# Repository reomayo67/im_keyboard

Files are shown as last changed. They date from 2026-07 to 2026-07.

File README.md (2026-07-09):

# im_keyboard

 33% ergonomic layout Keyboard. Atmega32u4 powered



HAS NOT BEEN ASSEMBLED YET

ALOT of this is heaviliy inspired by ScottoKeebs, I am using his footprint and symbol libraries in kicad, so shoutout to him. He was a huge help in making this possible. [ScottoKeebs](https://github.com/joe-scotto/scottokeebs) Huge inspo from [Plaid](https://github.com/hsgw/plaid)

So I just wanted to make an intro into the hardware engineering space with a simple pcb mkb. This is my first ever officially documented project, so yea. Ive been wanting to make one for a while, and eventually want to evolve into making abuncha wacky ergo keyboards and other stuff like that.

this keyboard uses only through hole components and relies on a devboard. Any type of mx switch can be used, it is not hot swap ready though.





The Case is 3d printed, made with fusion360.

Here are the youtube videos i watched in order to make this

https://www.youtube.com/watch?v=7azQkSu0m_U&t=491s

https://www.youtube.com/watch?v=8WXpGTIbxlQ&t=3s

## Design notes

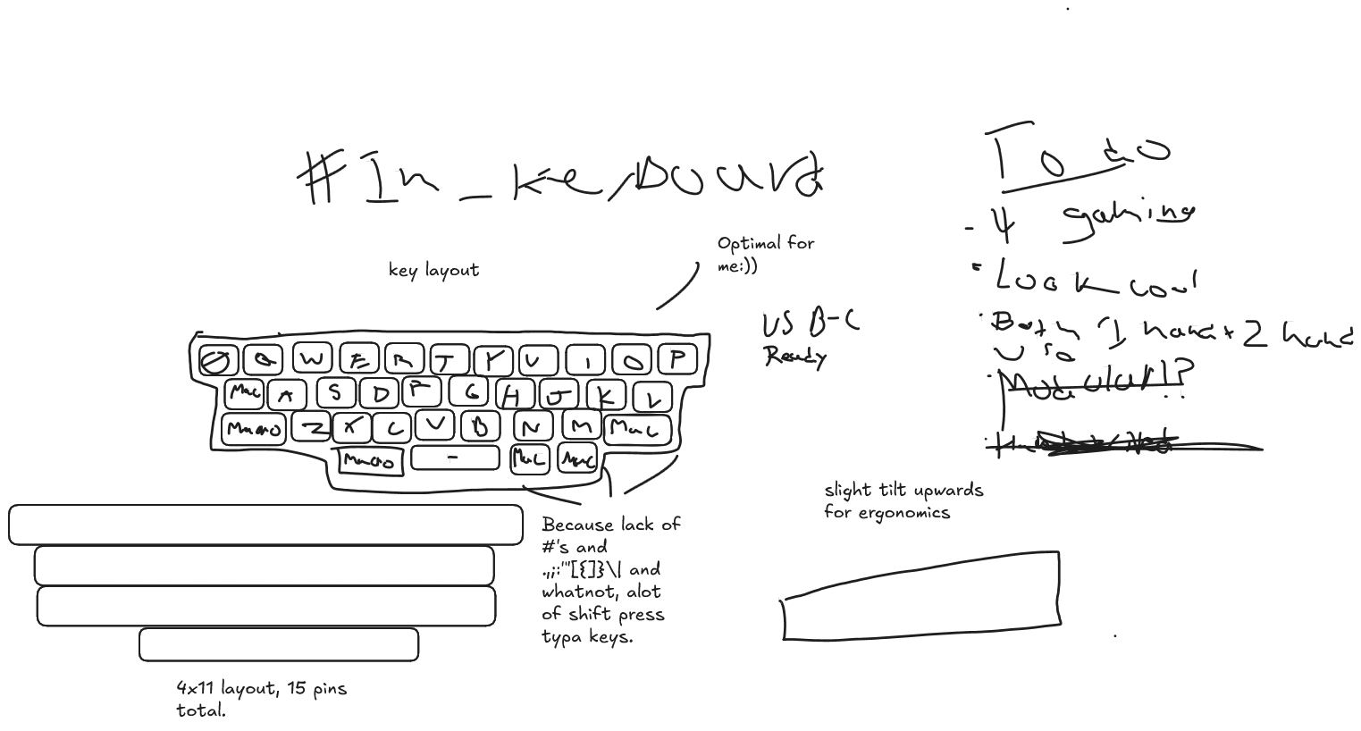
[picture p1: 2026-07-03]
#im_keyboard sketch #1.png

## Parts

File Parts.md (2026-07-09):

***Material Quantities***

M2 OD3.5mm L6mm Insert x3

M2 OD3.5mm L3mm Insert x2

M2 8mm screws x3

M2 8mm screws x2

2u stabilizers x3

3d printed Plate, Case, and Shell

PCB from JLCPCB .(Thats the manu im gonna use, if using another format gerber file to their sepcifics.)

ATMEGA32u4 w/ through hole mounts x1

34 of any Standard MX Switch.



Here is a list of where you may be able to purchase these parts.

|Parts|Link|
|---|---|
|M2 OD3.5mm L6mm Insert|[Here](https://www.aliexpress.us/item/3256803396040989.html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)|
|M2 OD3.5mm L3mm Insert|[Here](https://www.aliexpress.us/item/3256803396040989.html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)
|M2 4mm screws|[Here](https://www.aliexpress.us/item/3256808523663879.html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)
|M2 8mm screws|[Here](https://www.aliexpress.us/item/3256808523663879.html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)
|ATMEGA32u4|[Here](https://www.aliexpress.us/item/3256806468327207.html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)
|1N4148 Diodes|[Here](https://www.aliexpress.us/item/2255800939822415.html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)
|Stabilizers|[Here](https://www.aliexpress.us/item/2255800939822415.html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)
|ATMEGA32u4|[Here](https://www.aliexpress.us/item/3256812441376085.html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)

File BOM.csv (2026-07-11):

Part | Qnty | Where?
M2 OD3.5mm L6mm Insert | 3 | https://www.aliexpress.us/item/3256803396040989.html?mp=1
M2 OD3.5mm L3mm Insert | 2 | https://www.aliexpress.us/item/3256803396040989.html?mp=1
M2 4mm screws | 2 | https://www.aliexpress.us/item/3256808523663879.html?mp=1
M2 8mm screws | 3 | https://www.aliexpress.us/item/3256808523663879.html?mp=1
ATMEGA32u4 Dev Board(TYPE-C) | 1 | https://www.aliexpress.us/item/3256806468327207.html?curPageLogUid=WPj2RIIdIacO
1N4148 Diodes | 34 | https://www.aliexpress.us/item/2255800939822415.html?curPageLogUid=1XlJgsHdng42
2.00u Stabilizers | 3 | https://www.aliexpress.us/item/2255800939822415.html?curPageLogUid=1XlJgsHdng42

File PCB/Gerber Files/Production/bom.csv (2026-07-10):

Designator | Footprint | Quantity | Value | LCSC Part #
D1, D10, D11, D12, D13, D14, D15, D16, D17, D18, D19, D2, D20, D21, D22, D23, D24, D25, D26, D27, D28, D29, D3, D30, D31, D32, D33, D34, D4, D5, D6, D7, D8, D9 | Diode_DO-35 | 34 | ~
S1, S10, S11, S12, S13, S14, S15, S16, S17, S18, S19, S2, S20, S21, S22, S23, S24, S25, S26, S27, S28, S29, S3, S30, S31, S32, S33, S34, S4, S5, S6, S7, S8, S9 | MX_PCB_1.00u | 34 | ~
U1 | Arduino_Pro_Micro | 1 | Arduino_Pro_Micro

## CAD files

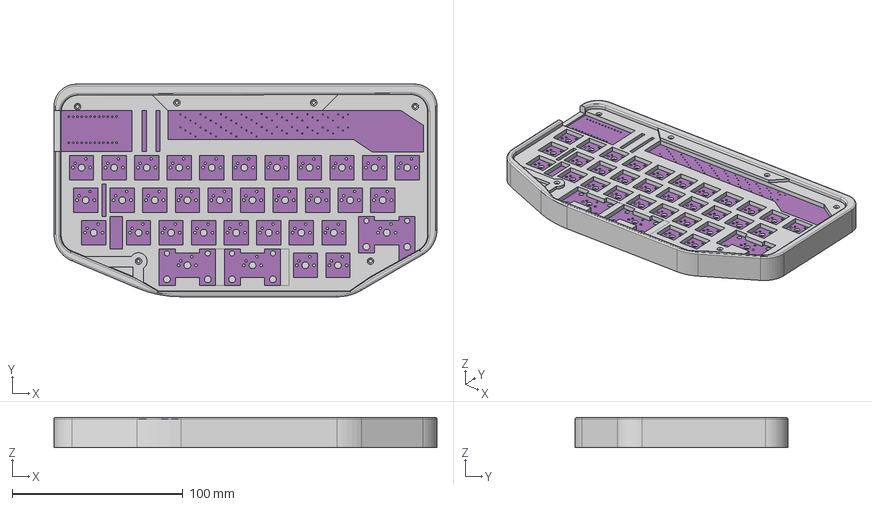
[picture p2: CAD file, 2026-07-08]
CAD/#Im_Keyboard case whole.step
224.1 x 124.4 x 17.7 mm
#im_keyboard_soldermask
#im_keyboard_PCB
#im_keyboard_soldermask_1

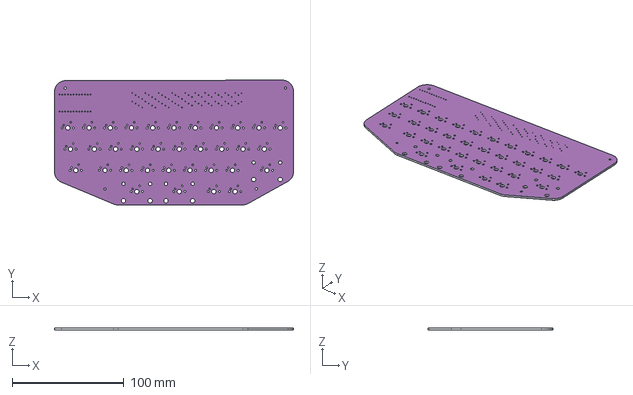
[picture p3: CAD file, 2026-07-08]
.step
214.3 x 111.9 x 1.61 mm
#im_keyboard_soldermask x 2
#im_keyboard_PCB

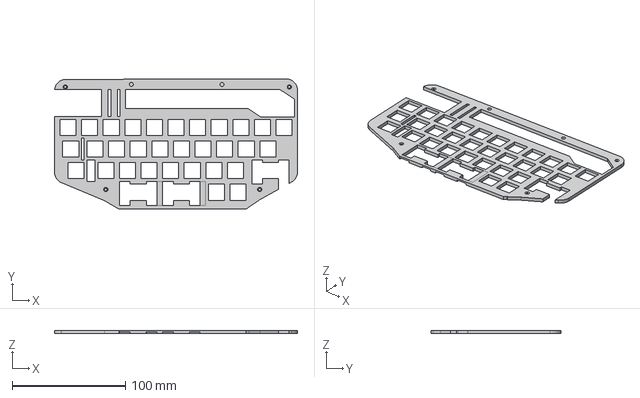
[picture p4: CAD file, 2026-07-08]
CAD/Case Plate.step
214.3 x 114.9 x 3.06 mm

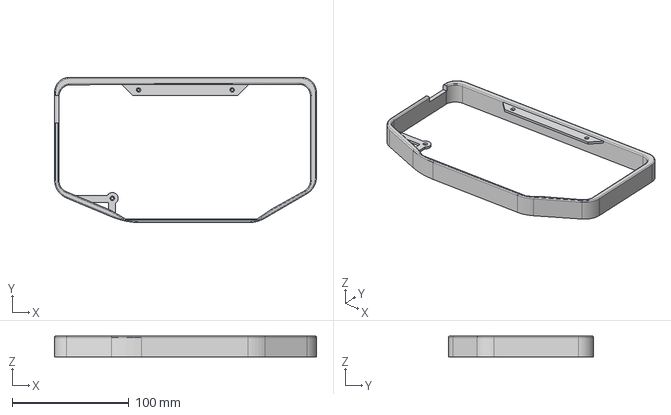
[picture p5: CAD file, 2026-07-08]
CAD/Case Shell.step
224.1 x 124.4 x 17.7 mm

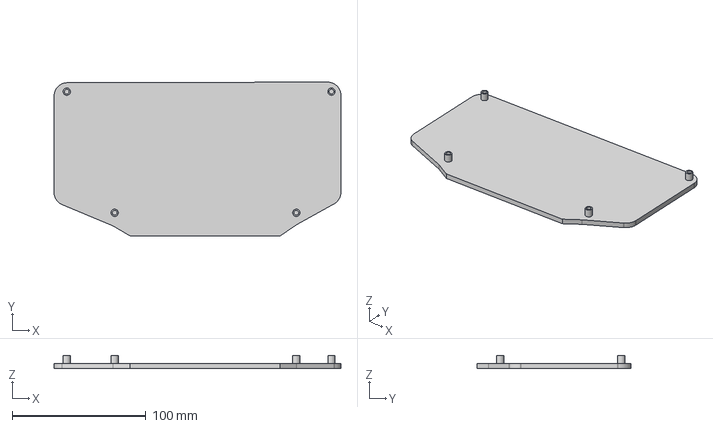
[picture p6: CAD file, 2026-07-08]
CAD/Case Base.step
214.3 x 114.9 x 10.0 mm

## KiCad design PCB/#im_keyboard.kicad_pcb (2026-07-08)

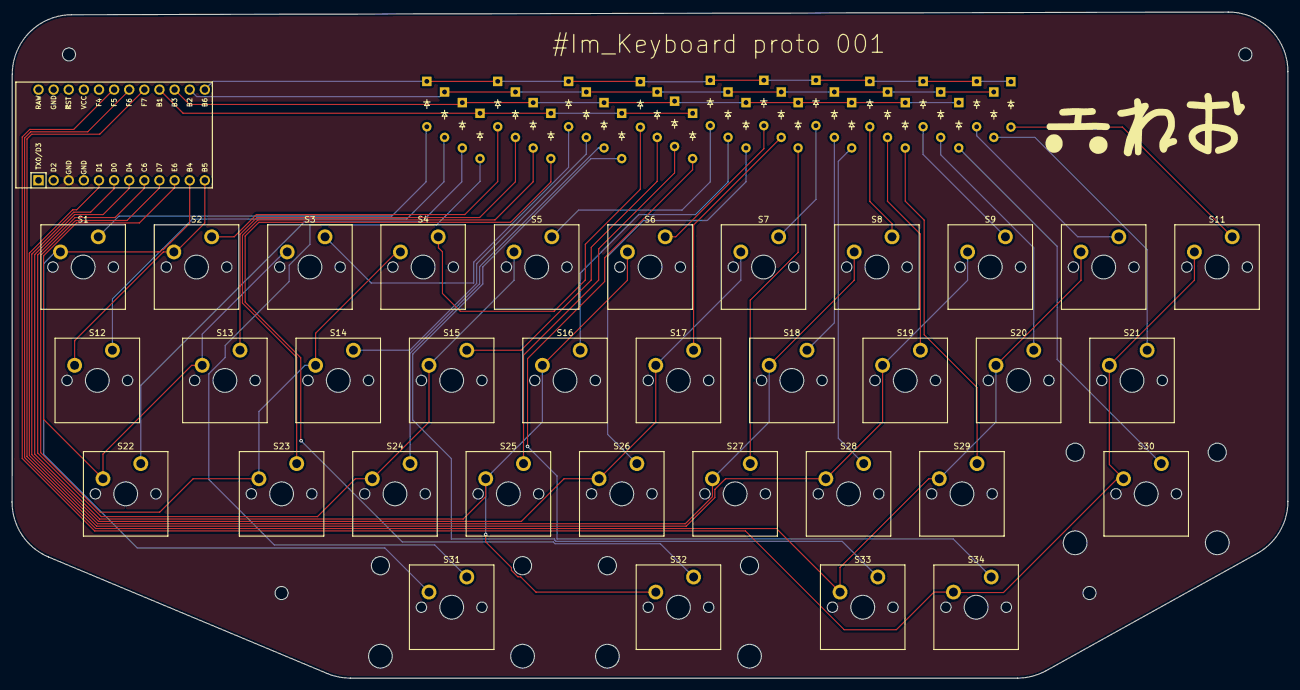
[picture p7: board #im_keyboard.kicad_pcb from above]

Board: 2 copper layers, 214.3 x 111.9 mm, 73 parts (0 on the bottom side), 49 nets.

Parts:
D1, D2, D3, D4, D5, D6, D7, D8, D9, D10, D11, D12, D13, D14, D15, D16, D17, D18, D19, D20, D21, D22, D23, D24, D25, D26, D27, D28, D29, D30, D31, D32, D33, D34: Diode_DO-35
H1, H2, H3, H4: MountingHole; MountingHole_2.2mm_M2
S1, S2, S3, S4, S5, S6, S7, S8, S9, S10, S11, S12, S13, S14, S15, S16, S17, S18, S19, S20, S21, S22, S23, S24, S25, S26, S27, S28, S29, S30, S31, S32, S33, S34: MX_PCB_1.00u
U1: Arduino_Pro_Micro

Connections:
Col0: S1.1, S31.1, U1.11 (8/PB4)
Col1: S2.1, S12.1, U1.12 (9/PB5)
Col2: S3.1, S13.1, S22.1, U1.10 (7/PE6)
Col3: S4.1, S14.1, S23.1, U1.9 (6/PD7)
Col4: S5.1, S15.1, S24.1, U1.8 (5/PC6)
Col5: S6.1, S16.1, S25.1, S32.1, U1.7 (4/PD4)
Col6: S7.1, S17.1, S26.1, U1.6 (3/PD0)
Col7: S8.1, S18.1, S27.1, U1.5 (2/PD1)
Col8: S9.1, S19.1, S28.1, U1.17 (A0/PF7)
Col9: S10.1, S20.1, S29.1, S33.1, U1.18 (A1/PF6)
Col10: S11.1, S21.1, S30.1, S34.1, U1.19 (A2/PF5)
unnamed: D1.2 (A), S1.2
unnamed: D2.2 (A), S2.2
unnamed: D3.2 (A), S3.2
unnamed: D4.2 (A), S4.2
unnamed: D5.2 (A), S5.2
unnamed: D6.2 (A), S6.2
unnamed: D7.2 (A), S7.2
unnamed: D8.2 (A), S8.2
unnamed: D9.2 (A), S9.2
unnamed: D10.2 (A), S10.2
unnamed: D11.2 (A), S11.2
unnamed: D12.2 (A), S12.2
unnamed: D13.2 (A), S13.2
unnamed: D14.2 (A), S14.2
unnamed: D15.2 (A), S15.2
unnamed: D16.2 (A), S16.2
unnamed: D17.2 (A), S17.2
unnamed: D18.2 (A), S18.2
unnamed: D19.2 (A), S19.2
unnamed: D20.2 (A), S20.2
unnamed: D21.2 (A), S21.2
unnamed: D22.2 (A), S22.2
unnamed: D23.2 (A), S23.2
unnamed: D24.2 (A), S24.2
unnamed: D25.2 (A), S25.2
unnamed: D26.2 (A), S26.2
unnamed: D27.2 (A), S27.2
unnamed: D28.2 (A), S28.2
unnamed: D29.2 (A), S29.2
unnamed: D30.2 (A), S30.2
unnamed: D31.2 (A), S31.2
unnamed: D32.2 (A), S32.2
unnamed: D33.2 (A), S33.2
unnamed: D34.2 (A), S34.2
Row0: D1.1 (K), D2.1 (K), D3.1 (K), D4.1 (K), D5.1 (K), D6.1 (K), D7.1 (K), D8.1 (K), D9.1 (K), D10.1 (K), D11.1 (K), U1.13 (10/PB6)
Row1: D12.1 (K), D13.1 (K), D14.1 (K), D15.1 (K), D16.1 (K), D17.1 (K), D18.1 (K), D19.1 (K), D20.1 (K), D21.1 (K), U1.14 (16/PB2)
Row2: D22.1 (K), D23.1 (K), D24.1 (K), D25.1 (K), D26.1 (K), D27.1 (K), D28.1 (K), D29.1 (K), D30.1 (K), U1.15 (14/PB3)
Row3: D31.1 (K), D32.1 (K), D33.1 (K), D34.1 (K), U1.16 (15/PB1)

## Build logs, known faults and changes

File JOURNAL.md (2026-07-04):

Overall, I am very new to anything related to this. This is my first project ever, so alot of trial and error. Like any engineering project ;)

July 3rd

Ive gotten foundations of kicad down, how to make schematics, what they mean , and how to use it basically.
I also found out that the keycaps I am using are proportionate to eachother :D, which makes for less headache later.
I made a rough schematic based on the fact that i have a ATMega32u4 and based off of my sketch,.

This is the original intended key layout:



And this is the key layout that I made based on the given sketch.



by looking at my current keyboard, I found that for the letters, each shift down a row will shift all of the keys to the right about 2.8mm, and continue proportionally. using that knowledge, I made the classic ergonomic key layout that is suited for typing. the spacebar incorperates a shift key size, shift/enter uses a tab, and caps lock and tab are only your standard key size.

Ive arranged the diodes to look like a zig zag.



Now, although it looks cool, it will be harder to implement the wiring within the pcb. Thats a challenge I am willing to take.
I also decided to eventually flip the diodes so the wire lengths would be shorter, as well as trying to save space by squishing them together.
Overall, I got the very basics of a board done today.

July 4th

After looking at plaids pcb, im gonna use his idea of alternatying between top cu adn bottom cu for the diode intersections.



As you can see, he rotates between the two copper layers to allow for all the diodes to coexist in such a tiny area without conflict.
I got all of the columns wired together and connected the the mcu, as well as the first row connected to their diodes. I will have to use vias to be able to organize the tracks so they can coexist peacfully.

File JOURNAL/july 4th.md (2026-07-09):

July 4th

After looking at plaids pcb, im gonna use his idea of alternatying between top cu adn bottom cu for the diode intersections.



After thinking for a bit, I wanna use the rows that Plaid used for his diodes, as they are so organized and optimized. Other thn placing the diodes directly next to their switch

As you can see, he rotates between the two copper layers to allow for all the diodes to coexist in such a tiny area without conflict.
I got all of the columns wired together and connected the the mcu, as well as the first row connected to their diodes. I will have to use vias to be able to organize the tracks so they can coexist peacfully.

After some revisions of the diodes and to where they orintate, i got smth like this.



They are alligned so the top layer is row 1, second layer is row 2, and so on. And going right, are the keys in that row. So after alligning ALL of them to their switches and tracking the columns together, adding the inverted fill zone, and a general pcb cutout, I got this.



Now, as you can see, for the diode tracking I alternate between front cu and bottom cu so all the tracks can be around eachother in the same congested area with the diodes. I ran the DRC and didnt get any errors :D, but there are a couple warnings and other unchecked tests that I wanna dive deeper into before exporting the board. Allat is a task for tmrw.

Here is the 3d model with the visual renders of the components



Today was Chalk full of getting to know kicad better, which is amazing.

2 hours

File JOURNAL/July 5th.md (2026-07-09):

So, I basically had the bones of this board ready, so today I just worked on cleaning it up and making sure it was ready to be ordered.
I added m2 screw holes for mounting to the case, supports for the shift keys i was using. Required a lil rewiring around the holes made, as well as the implementation of a GRN Net. (idk how i didnt add one before :{...)


Here are the support holes, there were 3 total supports and I just used a premade footprint from ScottoKeebs.

I also added a copper fill zone on the ground net which resulted in some interesting things to happen.



So i was confused why this was happening, tried routing vias to somehow fill the big gaps left. Bu then i realized, its ground, so where the electricity would be disipated. electricity just couldnt get to those sealed of portions. Now this keyboard doesnt have any reliance on stable electric noise, which is what filling is good for, so i just decided to leave it cuz whats the worst that could happen.

After finishing all of that, I ran the DRC.



Yay!

Now Im no artist, but figured i had to make my board stand out and put my little mark on it. So i just slapped the board model on aswell as this logo i made.

Switch reo logo

Its a switch symbol followed by my name in japanese. (Pretty clever huh...).

And boom I think im happy enough to move on to case design and then building my board! heres the finished product.



I also changed the board and slikscreen color to look better. I think the purple and blue combo looks pretty swag if u ask me.



3 Hours

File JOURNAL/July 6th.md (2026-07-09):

Today I am going to focus on working on the switch plate for mkb. 
I started by just exporting the 3d step file from kicad thinking it was no big deal. 
I  used and am still using fusion 360 as of writing this. 
I tried to import the step file. A simple step file.
Nothing popped up. I tried again with an stl file, Nothing.
I removed ALL of the through hole models from the boards 3d model. nothing again.
I tried putting it into OnShape, and it works flawlessly?
now because it is a browser cad service, i assume there is a protocol to potatofye the heck out of whatever your modeling
and optimizes it while still keeeping it looking good.
So i just figured tha fusion 360 saw the file and ran straight errors because of how complex it was.
I tried to insert it as a mesh and this 10000 plus triangle behemoth was infront of me.



Makes sense.
So i just imported and then exported it through onshape and got a decent board model ready to use to make my case.



It worked.

Now because I couldnt find a certain tool that would allow me to preciscly allign objects together in fusion, I had to make a sketch for a one
key plate for one switch in order to make it perfectly alligned, extruded it and copy pasted it and alligned it flush to the orginal.





Do that for a bit and you get this.



Now, I havnt considered the stabalizers YET, but am think that i can just make some washers and adjust them by height.
The stabalizers I am getting are screw mounted BTW.

Now all in all, today was super frustrating as I spent a total of 4 hours fumbling around all these different softwares and youtube videos
JUST so i could start the actual work that I was meaning to do. The plate part took abt 2 hours.
CYA next time.

2 Hours

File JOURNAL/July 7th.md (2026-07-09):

I hade a pretty good base to start with today, the switch mounts were all in place, and all I had to do was
fuse together the plate, make a bottom and shell for the case, and boom id be done.
Originally, I had thought of making a topmounted plate, meaning that the keys wouldnt have any thing sorrounding them and would
just be sticking up from the keyboard, and its really easy

However, I just settled on making a shell that would make it look really good, and add more layers and hopefully stability to 
the keyboard.

I wanted to first make the outline of the shell, so i extruded cut out a hole from a part with the bottom of the pcb, split
and deleted all of the pillars made from the holes in the pcb, and had a indented block in which my pcb would fit.

As i was deciding how to do this, I gained inspo from my keyboard that has points around the keyboard where the shell can sit on top of
and that makes it look nice



PLATE DESIGN

For making the plate, i just extruded a bunch of material outward so it could be cut by the pcb outline, then cut it. I ended up with this.



Now with this, I cut holes where the holes on the pcb should be, and made some cool design choices on the parts where the diodes and mcu are exposed.



I also made counter sunk screw holes, Because thats what I eventually ended up deciding what to use. So I cut thoseand found out that cad has a really nice feature, literally called Hole, that makes nice screw holes, especially for counter sunk ones.
The screw will be screwd into inserts, which will be on the Bottom. epeic transition

CASE BOTTOM DESIGN

Im using some m2 screw inserts from aliexpress and based these holes off of these dimensions



Im using both the OD3.5 L6 and L3, the l6s will be used to screw the plat, pcb, and bottom together, and the L3s will be used to secure the shell and plate together. I also chose 8 m screws, so i uncluded the depth of all the penetrata and should be left with about a couple mm of space in the inserts. (Better safe than sorry)

I made little walls to hold the inserts in place. prolly wit da supa glue



Man that bottom is pretty dope, do you wanna know what else is dope, eggs. What do eggs have?, shells. transition master god pro lvl 99 mafia boss

SHELL DESIGN.

I started with the outline of the board that i got, and still had to shape the outside.

So after drawing a couple lines and filleting the corners I just eyeballed the amount for each corner and to what looked good in my eyes.
I also made a cutout for the MCU so it could be plugged in hassle free. Since it is allready raised by the through hole extender beam things it should be and issue, even without the cutout

.

then I needed a way to mount the shell to the actuall board body itself. So i made some extensions from the inside of the shell, in which one overlaps with anoher screw hole. With that, I used the hole tool to make another counter sink, so I can just use the same hole but a longer screw,(abt 3 inches longher since thats how thiccc the extension is). With the other two, I just extended a long strip from the top mid of my shell and made their own screw holes, they go into the plate. In shich I will be mounting smaller screw inserts for.



this Shell is partly inspired by my royale kludge R75, in white, which has a fillet indent going around the trim of the shell, and is what I attempted to recreate.

I just filleted the outside into a nice curve instead. the case is 3 mm higher than the plate, and shouldnt clip with any of the keys.
After that, I slightly scaled the shell part by like 1.001 to account for 3d print innacuracy, as before this thang was an airtight seal.
And thats the case done. Prolly took like 1-2 hours right? It took 6. :( and i accidentaly closed my stardance tab for lookout. Whelp.

5 Hours Spent

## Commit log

2026-07-08 Create pcb
2026-07-08 Create cad
2026-07-08 Rename #Im_Keyboard case whole.step to CAD/#Im_Keyboard case whole.step
    [#Im_Keyboard case whole.step]
2026-07-08 Rename Case Base.step to CAD/Case Base.step
    [Case Base.step]
2026-07-09 Added Gerbers
    [#im_keyboard-B_Cu.gbl, #im_keyboard-B_Mask.gbs, #im_keyboard-B_Paste.gbp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]
2026-07-11 Rename BOM - Sheet1(1).csv to BOM.csv
    [BOM.csv]
2026-07-11 Rename BOM - Sheet1(2).csv to BOM.csv
    [BOM.csv]
